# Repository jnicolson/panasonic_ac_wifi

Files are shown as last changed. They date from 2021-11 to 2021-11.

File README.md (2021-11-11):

# Panasonic Wifi Module

This is a hardware module designed to plug into the CN-CNT connector on compatible Panasonic Airconditing Units

This is designed to run the esphome-panasonic-ac ESPHome library created by DomiStyle (https://github.com/DomiStyle/esphome-panasonic-ac) and all credit for the software goes to DomiStyle and other contributors.  

A cable with a 5 pin JST PA connector on one end and a 4 pin Molex PicoBlade on the other is required.  The 12V from the CN-CNT connector is unused so is not connected.  You can buy 4 pin pre-crimped PicoBlade cables from the likes of Adafruit - crimping tiny connectors can be challenging so buying a pre-crimped tail and soldering it to longer wires with a JST PA connector on the other end is a good option.

Programming is done using a 6 pin programmer.  Any programmer which adheres to the ESPFlash convention should work.  A programmer designed by myself is available at https://go.jmn.id.au/espprog but there are others (e.g. [SuperHouse ESPF](https://github.com/SuperHouse/ESPF)).  Alternatively any serial adapter can be used, but the ESP32 will need to be put into boot mode manually by pulling GPIO0 to ground during startup.

The smallest component is the 0603 capacitors and resistors so with a steady hand it's not too difficult assembling by hand and reflowing with a toaster oven, frypan or similar.  Using a solder paste stencil is easier but it wouldn't be too hard to dispense the solder manually too.

This was developed in KiCAD 5.99 so the latest nightly build should be used until KiCAD 6 is formally released.

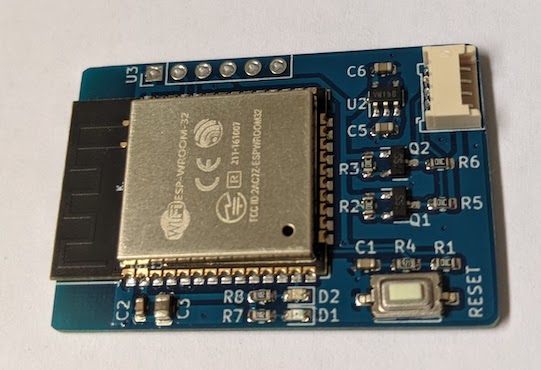
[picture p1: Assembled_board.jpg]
assembled board Assembled Board


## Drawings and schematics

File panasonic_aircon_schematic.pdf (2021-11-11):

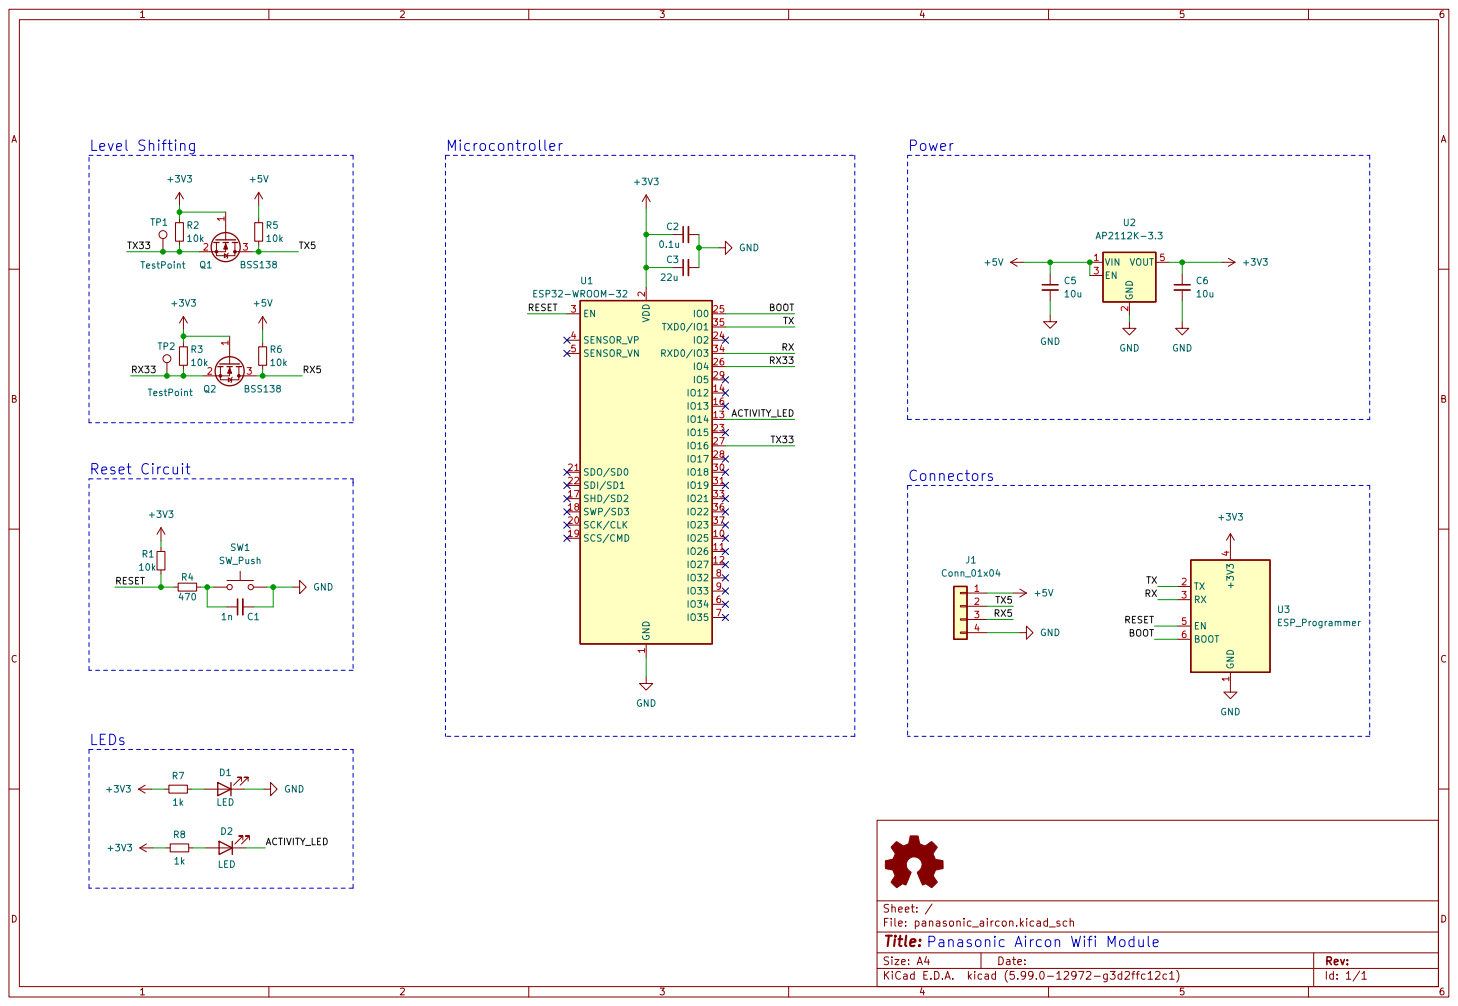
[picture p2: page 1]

2 EN 3 VOUT 5 U2 AP2112K-3.3 +3V3 GND GND

4 EN 5 BOOT 6 U3ESP_Programmer +3V3 VIN 1 GND

2 SCK/CLK 20 SDO/SD0 21 SDI/SD1 22

File: panasonic_aircon.kicad_sch Sheet: /
Id: 1/1 Title:
Panasonic Aircon Wifi Module

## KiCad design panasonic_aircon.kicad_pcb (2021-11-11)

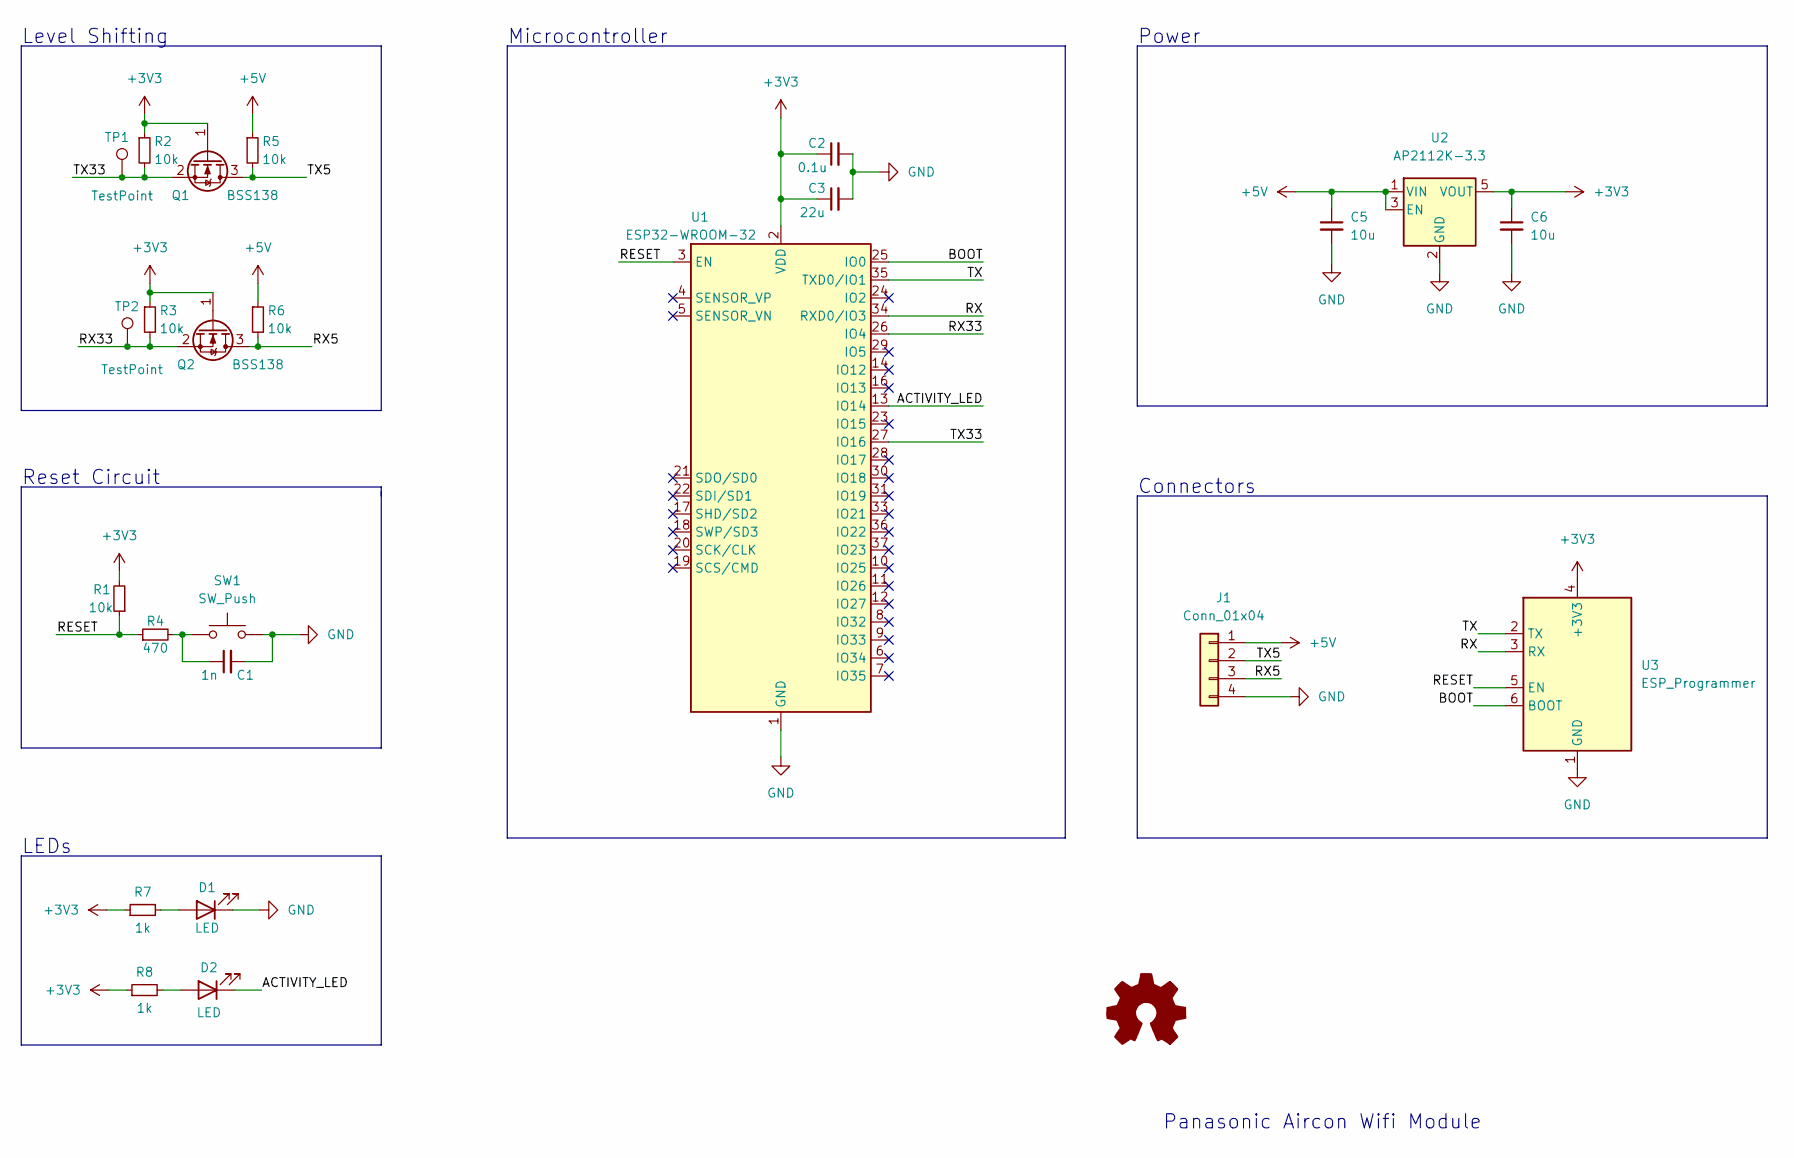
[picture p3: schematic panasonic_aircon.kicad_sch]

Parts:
C1: 1n; C_0603_1608Metric
C2: 0.1u; C_0603_1608Metric
C3: 22u; C_0805_2012Metric
C5, C6: 10u; C_0603_1608Metric
D1, D2: LED; LED_0603_1608Metric
J1: Conn_01x04; Molex_PicoBlade_53048-0410_1x04_P1.25mm_Horizontal
Q1, Q2: BSS138; SOT-23
R1, R2, R3, R5, R6: 10k; R_0603_1608Metric
R4: 470; R_0603_1608Metric
R7, R8: 1k; R_0603_1608Metric
SW1: SW_Push; SW_SPST_TS_1101_X_X
TP1, TP2: TestPoint; TestPoint_Pad_D1.5mm
U1: ESP32-WROOM-32
U2: AP2112K-3.3; SOT-23-5
U3: ESP_Programmer; PinHeader_1x06_P2.54mm_Vertical

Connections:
+3V3: C2.1, C3.1, C6.1, Q1.1 (G), Q2.1 (G), R1.2, R2.1, R3.1, R7.1, R8.1, U1.2 (VDD), U2.5 (VOUT), U3.4 (+3V3)
+5V: C5.1, J1.1, R5.1, R6.1, U2.1 (VIN), U2.3 (EN)
/ACTIVITY_LED: D2.1 (K), U1.13 (IO14)
/BOOT: U1.25 (IO0), U3.6 (BOOT)
/RESET: R1.1, R4.1, U1.3 (EN), U3.5 (EN)
/RX: U1.34 (RXD0/IO3), U3.3 (RX)
/RX5: J1.3, Q2.3 (D), R6.2
/RX33: Q2.2 (S), R3.2, TP2.1, U1.26 (IO4)
/TX: U1.35 (TXD0/IO1), U3.2 (TX)
/TX5: J1.2, Q1.3 (D), R5.2
/TX33: Q1.2 (S), R2.2, TP1.1, U1.27 (IO16)
GND: C1.2, C2.2, C3.2, C5.2, C6.2, D1.1 (K), J1.4, SW1.2, U1.1 (GND), U1.15 (GND), U1.38 (GND), U1.39 (GND), U2.2 (GND), U3.1 (GND)
unnamed: C1.1, R4.2, SW1.1
unnamed: D1.2 (A), R7.2
unnamed: D2.2 (A), R8.2

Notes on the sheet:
Level Shifting
Reset Circuit
LEDs
Microcontroller
Power
Connectors
Panasonic Aircon Wifi Module

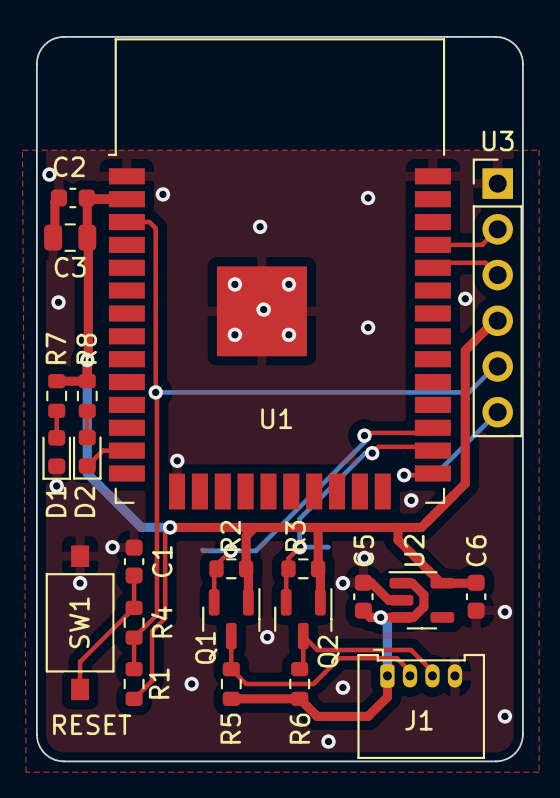
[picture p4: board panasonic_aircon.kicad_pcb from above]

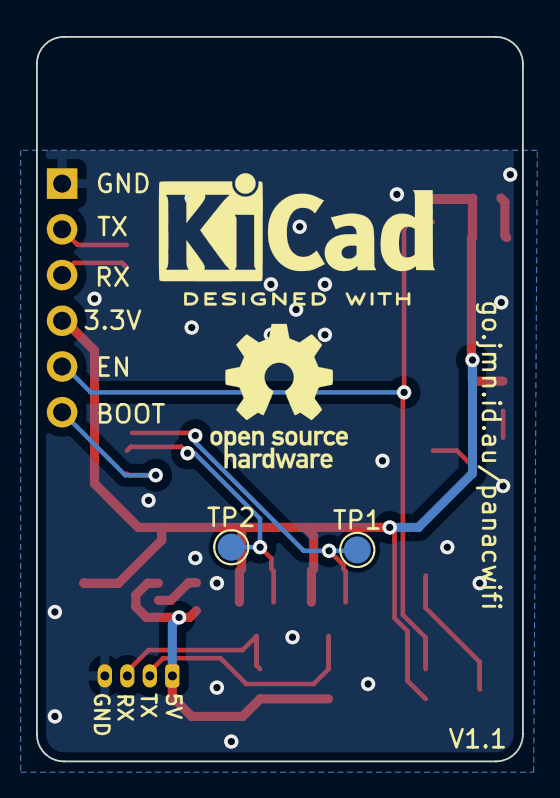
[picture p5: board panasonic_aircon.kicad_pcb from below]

Board: 2 copper layers, 27.0 x 40.2 mm, 24 parts (2 on the bottom side), 15 nets.

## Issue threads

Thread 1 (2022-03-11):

Requesting some infos

Stinocon, 2022-03-11:
Wow!
This project seems to be right up my alley! I have two Panasonic CZ-TACG1's built into Home Assistant but as we know they are not very reliable.
I was a bit put off by the other projects because I'm not very good at soldering but if I understand correctly I should just get this one manufactured, get a cable, put ESPHome in it and plug it in. That's it.

I have some questions:

1) Can you link me where exactly to buy the cable that is needed? Or at least a picture of the two ends so I can look for it in some EU store.
2) To flash other ESP modules I normally use dupont cables (I think they are called like that) and then connect them to a USB programmer... Does this work in the same way? I guess I have to use the PINs on the "white" connector.

Thanks!

jnicolson, 2022-03-12:
Hi,
Yes in theory someone like JLCPCB and their assembly service should be able to assemble this for you - I assembled this myself but all the parts were from LCSC so i think that means they should all be available at JLC (and there's probably others - JLC is just the one i'm aware of).

I don't think you could buy a pre-made cable unfortuantely.  The picoblade end you can - something like this: https://www.adafruit.com/product/4722 the female end should plug straight in to controller board.  For the air conditioner end, JST PA doesn't seem to be very popular with makers, it's easy to get JST-PH cables but not JST-PA.  If you really wanted to avoid crimping you could probably buy something like https://www.digikey.com/en/products/detail/jst-sales-america-inc/APAPA22K152/6009461 along with the housing https://www.digikey.com/en/products/detail/jst-sales-america-inc/PAP-05V-S/759977 .  You would then just need to join the picoblade tail to the JST-PA jumpers and insert them into the housing (making sure the get the pinout correct).  Joining them I would solder but if you're really against soldering then you could use a wago connector without issue.

To flash you could insert dupont connectors into the header to the right of the ESP32 - if you have an ESP32 type programmer then you don't need to do anything but if it's just a USB to serial adapter then you'll have to put it into programming mode manually (pull IO0/BOOT to ground by connecting a jumper between them then pull RESET to ground to reset it into boot mode).  It'd be a bit difficult as you would need to keep pressure on dupont connectors to make contact but you only have to do it once I guess?

Hope this answers your questions!

Romkabouter, 2023-08-24:
I have order 5 units from JLCPCB and I can confirm they work.
You should however use GPIO4 fro RX and GPIO16 for TX, this can also be found in the schematic

This was my order.
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

I have installed 1 in an airco, but need some connectors to install the second.
Integrates fine with HA

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

Romkabouter, 2023-08-24:
Note that my units have a header on U3

Romkabouter, 2023-08-25:
Sure, I ran into so problems with the positioning so I will try and fix that. Other people should be able to upload and order without those issues :)

Romkabouter, 2023-08-25:
Attached is a gerberfiles.zip, this includes the drill files and all. Also attached is a bom.csv (bill of materials) and a cpl.csv (the position file)
[bom.csv](https://github.com/jnicolson/panasonic_ac_wifi/files/12438439/bom.csv)
[cpl.csv](https://github.com/jnicolson/panasonic_ac_wifi/files/12438440/cpl.csv)
[gerberfiles.zip](https://github.com/jnicolson/panasonic_ac_wifi/files/12438441/gerberfiles.zip)

Romkabouter, 2023-08-26:
This is my config:

```
esphome:

  name: airco-bedroom
  friendly_name: Airco bedroom

esp32:
  board: esp32dev
  framework:
    type: arduino

# Enable logging
logger:

# Enable Home Assistant API
api:
  encryption:
    key: !secret encryption_key

ota:
  password: !secret wifi_password

wifi:
  ssid: !secret wifi_ssid
  password: !secret wifi_password

  # Enable fallback hotspot (captive portal) in case wifi connection fails
  ap:
    ssid: "Airco-Bedroom Fallback Hotspot"
    password: "vRXDT1a6XiNW"

captive_portal:

uart:
  tx_pin: GPIO16
  rx_pin: GPIO4
  baud_rate: 9600
  parity: EVEN

external_components:
  source: github://DomiStyle/esphome-panasonic-ac
  components: [panasonic_ac]

climate:
  - platform: panasonic_ac
    type: cnt
    name: AC Bedroom
    horizontal_swing_select:
      name: AC Bedroom Horizontal Swing Mode
    vertical_swing_select:
      name: AC Bedroom Vertical Swing Mode
    outside_temperature:
      name: AC Bedroom Outside Temperature
    current_power_consumption:
      name: AC Bedroom Power Consumption
```

Romkabouter, 2023-08-31:
I have ordered a 4 pin molex from here:
https://nl.aliexpress.com/item/1005004538678776.html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

And the JST-PA from here
https://nl.aliexpress.com/item/1005005390614645.html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

My plan is to connect them for my other 4 units, one is with some soldered wire.

mistaoh, 2023-09-04:
I ended up buying https://mou.sr/45C09PS premade cable assembly with the molex picoblade and a JST-PA crimp kit https://www.cqrobot.com/index.php?route=product/product&product_id=1485

Sh1bbyz, 2023-12-07:
> Attached is a gerberfiles.zip, this includes the drill files and all. Also attached is a bom.csv (bill of materials) and a cpl.csv (the position file) [bom.csv](https://github.com/jnicolson/panasonic_ac_wifi/files/12438439/bom.csv) [cpl.csv](https://github.com/jnicolson/panasonic_ac_wifi/files/12438440/cpl.csv) [gerberfiles.zip](https://github.com/jnicolson/panasonic_ac_wifi/files/12438441/gerberfiles.zip)

Hello @Romkabouter !

Thank you so much for this! This seems exactly what I am after!
I am about to order this but have some doubts.
Mainly I am worried that the connector for SW1 is missing from the BOM? It seems from your picture that you have something there?

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

Thank you in advance and forgive me for my incompetence in this!

Sh1bbyz, 2023-12-07:
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

Sure, I am interested! I live in Sweden.
I couldnt figure out how to PM here but please email me at 96k0xgsf@duck.com.

Thanks!

codyc1515, 2023-12-07:
I would be interested to purchase one also.

Romkabouter, 2023-12-09:
> I would be interested to purchase one also.

Hi @codyc1515, I am sorry but just while you send this message I sold all three of them.
Sorry about that

brasdata, 2023-12-13:
Hi, what is the part number of the missing switch?

jnicolson, 2023-12-13:
> Hi, what is the part number of the missing switch?

When I populated mine, I used LCSC part C500065 (https://www.lcsc.com/product-detail/_XKB-Connectivity-_C500065.html).  I assembled mine manually so bought from LCSC, but JLCPCB have it in their parts library.

Romkabouter, 2023-12-13:
> Hi, what is the part number of the missing switch?

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

tech1977, 2024-11-21:
does anyone have one available for sale?
thanks

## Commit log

2021-10-04 Straight to Revision 1.1 - forgot to create repository before
    [panasonic_aircon.kicad_pcb, panasonic_aircon.kicad_sch]
2021-11-11 Cleanup Schematic layout, label each section
    [panasonic_aircon.kicad_sch]
2021-11-11 Small update to edge of board
    [panasonic_aircon.kicad_pcb]
2021-11-11 Add schematic PDF document
2021-11-11 Update README and add image of finished board
